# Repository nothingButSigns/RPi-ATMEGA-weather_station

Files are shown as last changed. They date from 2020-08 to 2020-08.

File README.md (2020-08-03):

# RPi-ATMEGA weather station
Project of weather station involving RPi, AVR microcontroller ATMEGA329P and radio transmission

The project concerns electronical and programming aspect of weather station.
The station itself is based on AVR microcontroller - ATMEGA 328p and set of sensors which allow to collect following data:
* temperature [°C]
* humidity [%RH]
* pressure [hPa]
* luminosity [lux]
* wind direction and wind speed [m/s]

The data is read every 1 h and sent via nRF24L01+PA radio tranceiver to Raspberry Pi 3B+ and saved in mysql database.

The repository contains eagle project of PCB board (THT) for the station and schematic. Libraries of parts which could not be found in EAGLE are included.

The project requires mySQL database to be installed on RPi.
MySQL database schema can be then imported with following terminal command:
```sh
$ mysql -u root -p [DB_NAME] < \path\user_name\Downloads\file.sql
```

C program (meteo_station.ino) was written in Arduino IDE 1.8.9.
Arduino bootloader was uploaded to ATMEGA 328P as instructed by [Nick Gammon](http://www.gammon.com.au/forum/?id=11637).
Following libraries are necessary:
* [Adafruit Sensor](https://github.com/adafruit/Adafruit_Sensor)
* [Wire](https://github.com/esp8266/Arduino/tree/master/libraries/Wire)
* [Adafruit BME280](https://github.com/adafruit/Adafruit_BME280_Library)
* [BH1750](https://github.com/claws/BH1750)
* [RF24](http://tmrh20.github.io/RF24)

C++ program written for RPi requires [RF24 library](https://github.com/nRF24/RF24) which contains essential dependencies (WiringPi & BCM2835) and [mySQL-cpp-connector] (https://dev.mysql.com/downloads/connector/cpp/)

The station is powered with 3.7 V NCR18650B connected to circuit via JACK socket. The battery is not included in schematic.

#BOM
| Q-ty | Part name | Value | Package | Description |
| --- | --- | ----- | --- | --- |
|1|ATMEGA328P|-|DIP|AVR Microcontroller|
|1|WIRELESS-NRF24L01-PA-EXT|-|-|2.4 GHz Wireless Module based on NRF24L01|
|1|BME280|-|-|Digital Humidity-Temperature-Pressure Sensor|
|1|BH1750|-|-|Digital Light Sensor|
|1|Lacrosse TX20|-|-|Wind speed and direction sensor|
|1|Quartz Crystal|8MHz|HC49/S|-|
|2|Electrolytic capacitor|0.1 uF|C2.5-3|-|
|1|Electrolytic capacitor|0.22 uF|C2.5-3|-|
|1|Electrolytic capacitor|4.7 uF|C2.5-3|-|
|2|Ceramic capacitor|22 pF|C2.5-3|-|
|3|Resistor|0 Ω |0204/5|-|
|1|Resistor|10 kΩ|0204/5|-|
|1|LFXXCVS|LF33CVS|TO220 S|Voltage regulator|
|1|JACK-PLUG|-|SPC4077|Plug to enable circuit powering with DC|
|1|4-pin terminal block|3.5 mm|-|Terminal block with round pad|

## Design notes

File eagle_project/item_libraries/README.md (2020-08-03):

Sources of used libraries:

https://www.diymodules.org/eagle
https://www.diymodules.org/eagle-show-library?id=1012211613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
https://github.com/shackspace/DARC/blob/master/doc/eagle/DARC/lf33.lbr

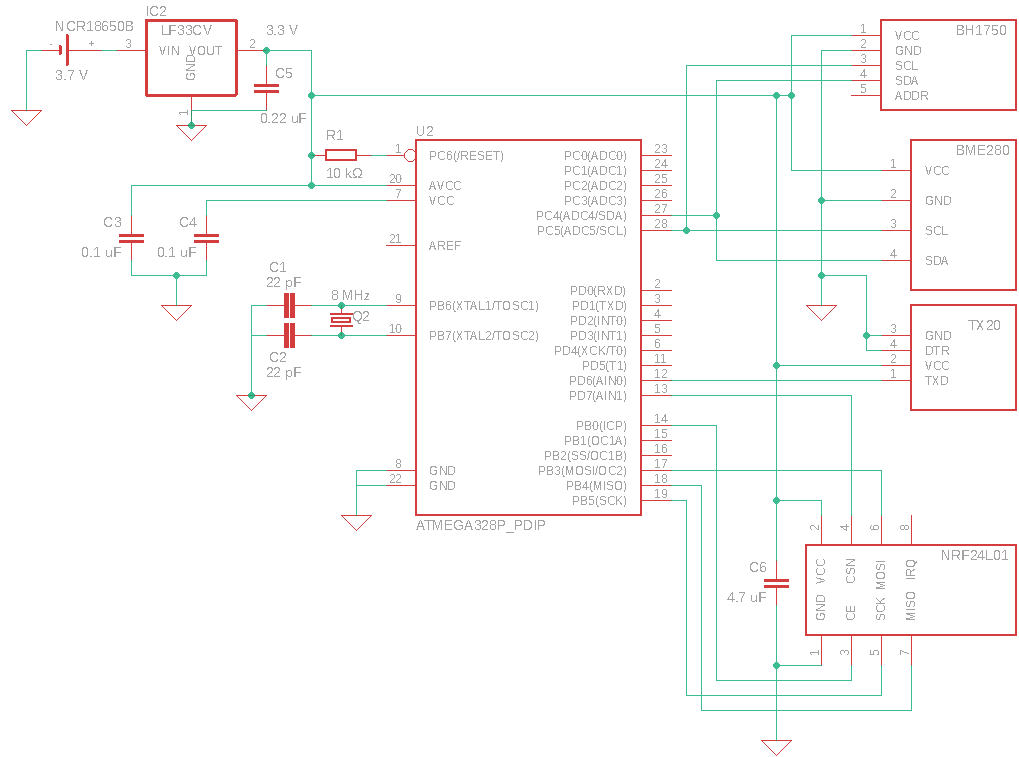
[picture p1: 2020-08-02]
eagle_project/schematic.png

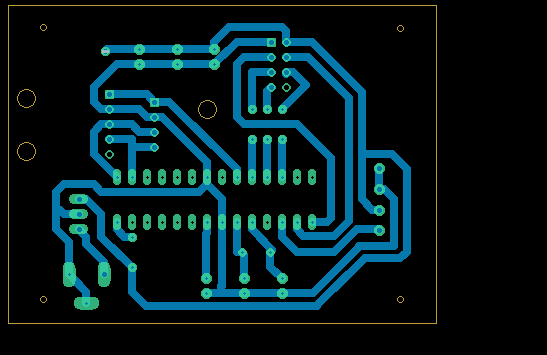
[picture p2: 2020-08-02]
eagle_project/board.png

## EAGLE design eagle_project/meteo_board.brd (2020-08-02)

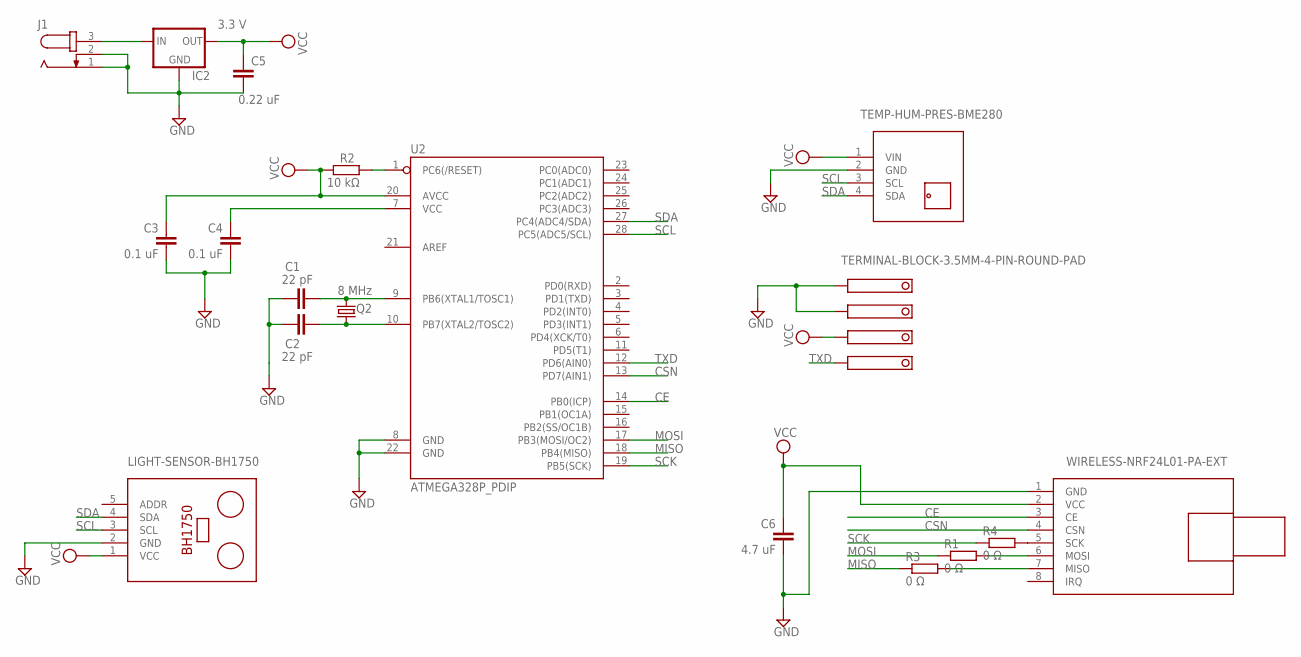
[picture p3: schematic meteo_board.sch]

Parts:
C1, C2: 22 pF; C2.5-3
C3, C4: 0.1 uF; C2.5-3
C5: 0.22 uF; C2.5-3
C6: 4.7 uF; C2.5-3
IC2: LFXXCVS; TO220S
J1: JACK-PLUG0; SPC4077
M1: WIRELESS-NRF24L01-PA-EXT
Q2: 8 MHz; HC49/S
R1, R3, R4: 0 Ω; 0204/5
R2: 10 kΩ; 0204/5
TX20: TERMINAL-BLOCK-3.5MM-4-PIN-ROUND-PAD; TERMINAL-BLOCK-4-PIN-3.5MM-ROUND-PAD
U2: ATMEGA328P_PDIP; DIL28-3
U$5: LIGHT-SENSOR-BH1750
U$6: TEMP-HUM-PRES-BME280

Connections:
CE: M1.3 (CE), U2.14 (PB0(ICP))
CSN: M1.4 (CSN), U2.13 (PD7(AIN1))
GND: C1.1, C2.1, C3.1, C4.1, C5.2, C6.1, IC2.2 (GND), J1.1, J1.2, M1.1 (GND), TX20.1, TX20.2, U2.8 (GND), U2.22 (GND), U$5.2 (GND), U$6.2 (GND)
MISO: R3.1, U2.18 (PB4(MISO))
MOSI: R1.1, U2.17 (PB3(MOSI/OC2))
unnamed: IC2.1 (IN), J1.3
unnamed: R2.2, U2.1 (PC6(/RESET))
unnamed: M1.5 (SCK), R4.2
unnamed: C1.2, Q2.2, U2.9 (PB6(XTAL1/TOSC1))
unnamed: C2.2, Q2.1, U2.10 (PB7(XTAL2/TOSC2))
unnamed: M1.6 (MOSI), R1.2
unnamed: M1.7 (MISO), R3.2
unnamed: C4.2, U2.7 (VCC)
SCK: R4.1, U2.19 (PB5(SCK))
SCL: U2.28 (PC5(ADC5/SCL)), U$5.3 (SCL), U$6.3 (SCL)
SDA: U2.27 (PC4(ADC4/SDA)), U$5.4 (SDA), U$6.4 (SDA)
TXD: TX20.4, U2.12 (PD6(AIN0))
VCC: C3.2, C5.1, C6.2, IC2.3 (OUT), M1.2 (VCC), R2.1, TX20.3, U2.20 (AVCC), U$5.1 (VCC), U$6.1 (VIN)

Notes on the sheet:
3.3 V

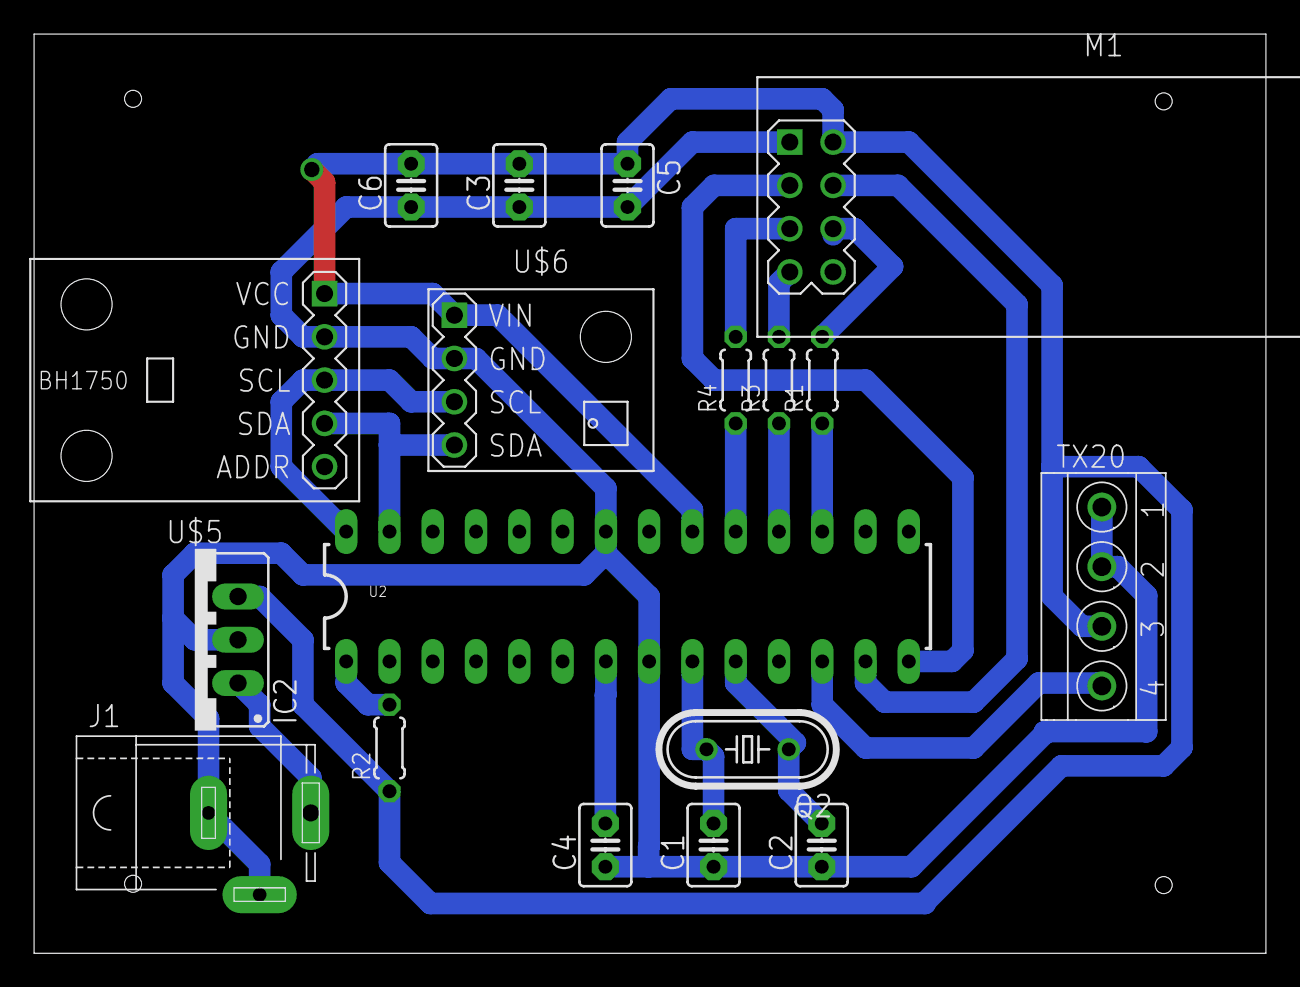
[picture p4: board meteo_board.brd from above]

Board: 2 copper layers, 72.3 x 54.0 mm, 18 parts (0 on the bottom side), 18 nets.

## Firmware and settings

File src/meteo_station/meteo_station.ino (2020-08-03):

#include <Wire.h>
#include <Adafruit_Sensor.h>
#include <Adafruit_BME280.h>
#include <BH1750.h>
#include <RF24.h>
#include <avr/sleep.h>
#include <avr/power.h>
#include <avr/wdt.h>

// define pin for Tx20
#define WINDpin 6
// define pins for nRF24L01+PA LNA
#define CE_PIN 8             
#define CSN_PIN 7
                 
const uint64_t transmit_pipe = 0xEEFDFDF0A2; // transmit pipe
RF24 radio(CE_PIN, CSN_PIN);

struct WeatherData {
    uint8_t lum;
    float temp;
    float hum;
    float press;
    float wind_speed;
    String wind_dir;
} weather;

Adafruit_BME280 bme;
BH1750 lightMeter;

unsigned long delayTime = 1000;
bool status;         // BME280 availability state ('true' if the sensor is available)
int bitlenght = -1;
bool data[41];
int watchdogIterations = 450;                  // number of WDT cycles to get ~1 h interval between data read
int currentIteration = watchdogIterations;     // enables data read right after powering on
byte adcsra = 0;


void delay2(unsigned long ms);
void getdata(void);
void interpretdata();

ISR(WDT_vect) {
   sleep_disable();               
   ADCSRA = adcsra;  // turn on ADC
}

void radiosetup()
{
  radio.powerUp();  
  radio.begin();
  radio.setCRCLength( RF24_CRC_16 ) ;
  radio.setDataRate( RF24_1MBPS );
  radio.setPayloadSize(32);
  radio.setChannel(0x4c);
  radio.setAutoAck( true ) ;
  radio.setPALevel( RF24_PA_HIGH ) ;
  radio.setRetries(5,15);
  radio.stopListening();
}

void setupSensors()
{
    radio.powerUp();
    void radiosetup();
    pinMode(WINDpin, INPUT);     
    Wire.begin();
    
    // set BH1750 sensor to read data once and go into sleep mode; set resolution to 4lx
    lightMeter.begin(BH1750::ONE_TIME_LOW_RES_MODE);
   
    status = bme.begin(0x76);
    if (!status) {
        while (1);
    }
}
  

void setup() { 
  // If reset occurs, check whether it was caused by WDT
  if(MCUSR & _BV(WDRF)) {
    MCUSR &= ~_BV(WDRF);              // reset reset-due-to-watchdog flag
    WDTCSR |= (_BV(WDCE) | _BV(WDE));  // enter watchdog configuration mode
    WDTCSR = 0x00;                     // disable WDT
  }  
  
  cli(); //disable interruptions
     
   WDTCSR |= (_BV(WDCE) | _BV(WDE));               // enter watchdog configuration mode
   WDTCSR =  _BV(WDIE) | _BV(WDP3) | _BV(WDP0);    // enable interrupts and set timer to ~8 sec
   wdt_reset();
  //re-enable interrupts    
  sei(); 
}

void loop() { 
  
  gotoSleep();
  
  if(++currentIteration >= watchdogIterations) {
    setupSensors();
    getdata();                                    
    interpretdata();                   
    weather.lum = lightMeter.readLightLevel(); 
    weather.temp = bme.readTemperature();        
    weather.press = bme.readPressure()/100.0;
    weather.hum = bme.readHumidity();

    radio.openWritingPipe(transmit_pipe);
    radio.write( &weather, sizeof(WeatherData)); 
    currentIteration = 1;
  }
   
}

// function to get datagram from Tx20
void getdata(){
  if (bitlenght <0){
     bitlenght = 1220; // duration of 1 bit [ms]
  }
 
   pinMode(WINDpin, OUTPUT);
   digitalWrite(WINDpin, HIGH);
   delay(100);
   
   digitalWrite(WINDpin, LOW );
   delay(500);
   
   pinMode(WINDpin, INPUT);
  
  
   while(digitalRead(WINDpin) == LOW){}  
   while(digitalRead(WINDpin) == HIGH){}
   while(digitalRead(WINDpin) == LOW){}

   for (int i=0 ; i<41 ; i++){  
     data[i] = (digitalRead(WINDpin) == LOW)? 0 : 1 ; 
     delay2(bitlenght);
 }

 interpretdata();
}

// function to retrieve wind speed and direction
void interpretdata(){
 
  // wind direction
  char DirBuffer = 0;
  for (int i =8 ; i> 4 ; i--){ 
    DirBuffer = DirBuffer << 1;
    DirBuffer |= (char)(data[i]^1);;
  }

   switch(DirBuffer) {
     case 0: weather.wind_dir="N"; break;
     case 1: weather.wind_dir="NNE"; break;;
     case 2: weather.wind_dir="NE"; break;
     case 3: weather.wind_dir="ENE"; break;
     case 4: weather.wind_dir="E"; break;
     case 5: weather.wind_dir="ESE"; break;
     case 6: weather.wind_dir="SE"; break;
     case 7: weather.wind_dir="SSE"; break;
     case 8: weather.wind_dir="S"; break;
     case 9: weather.wind_dir="SSW"; break;
     case 10: weather.wind_dir="SW"; break;
     case 11: weather.wind_dir="WSW"; break;
     case 12: weather.wind_dir="W"; break;
     case 13: weather.wind_dir="WNW"; break;
     case 14: weather.wind_dir="NW"; break;
     case 15: weather.wind_dir="NNW"; break;
   }

 
 int ws_buffer = 0;
 // wind speed data
 for (int i =9 ; i> 21 ; i++){
      ws_buffer |= (data[i]^1)<<(i-9);     
 }

 ws_buffer &=~(1<<11|1<<10|1<<9); 
 weather.wind_speed = ws_buffer * 0.1;  
}

void gotoSleep(void)
{
   adcsra = ADCSRA;                       // save ADC state
   ADCSRA = 0;                            // turn off ADC 
   set_sleep_mode(SLEEP_MODE_PWR_DOWN);   // use power down sleep mode
   sleep_enable();                        // enable sleep mode
   sleep_cpu();                   
}

void delay2(unsigned long ms){
  unsigned long start = micros();
  while (micros() - start <= ms);
}

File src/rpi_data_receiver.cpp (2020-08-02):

#include <mysql_connection.h>
#include <cppconn/driver.h>
#include <cppconn/statement.h>
#include <cppconn/exception.h>
#include <cppconn/prepared_statement.h>
#include <inttypes.h>

#include <RF24.h>
#include <wiringPi.h>

/* Create instance of class RF24 to receive radio data.
 * 	Connection of nRF24L01 transceiver module to RPi:
 *  CE -> RPI_V2_GPIO_P1_22
 *	CSN -> RPI_V2_GPIO_P1_24
 *	SPI speed [MHZ] -> BCM2835_SPI_SPEED_8MHZ
 */

RF24 radio(RPI_V2_GPIO_P1_22, RPI_V2_GPIO_P1_24, BCM2835_SPI_SPEED_8MHZ);
/* Writing/receiving pipes created according to nRF24L01 specification:
 * pipes[0] -> writing pipe
 * pipes[1] -> reading pipe; it's address is the same as address
 * of writing pipe in weather station
 */
const uint64_t pipes[2] = { 0xeefdfdf0ec, 0xa2ll};

/* Data to connect to mySQL database in order to save received data.
 * MYSQL_USER and MYSQL_PASSWD defines should be replaced with
 * Your own user data
 */
#define HOST "localhost"
#define MYSQL_USER "randomuser"
#define MYSQL_PASSWD "password"
#define MYSQL_DATABASE "sensor_data"

struct __attribute__((__packed__)) WeatherData {
	uint8_t lum;
    float temp;
    float hum;
    float press;
    float w_speed;
    const char* w_dir;
} weather;

void setup_radio()
{
  radio.begin();
  /* data below can be adjusted to acquire efficient
   * transmission in case-specific conditions
   * such as distance between weather station and receiver
   * or presence of any physical obstacles (e.g. walls)
   */
  radio.setPayloadSize(32);
  radio.setRetries(5,15);
  radio.setAutoAck(true);
  radio.setPALevel(RF24_PA_HIGH);
  radio.setChannel(0x4c);
  radio.setDataRate(RF24_1MBPS);
  radio.setCRCLength(RF24_CRC_16);
  delay(100);

      radio.openWritingPipe(pipes[0]);
      radio.openReadingPipe(1,pipes[1]);
}


void saveData(WeatherData *weather)
{
    sql::Driver * driver;
    sql::Connection *conn;
    sql::Statement *stat;
    sql::PreparedStatement *prep_stat;


    driver = get_driver_instance();
    conn = driver->connect(HOST, MYSQL_USER, MYSQL_PASSWD);
    stat = conn->createStatement();
    stat->execute("USE sensor_data");


            prep_stat = conn->prepareStatement("INSERT INTO weather_data(Date, Time, Temperature, Humidity, Pressure, Luminosity, Wind_dir, Wind_speed) VALUES(NOW(), NOW(),?, ?, ?, ?, ?, ?)");
            prep_stat->setDouble(1,(*weather).temp);
            prep_stat->setDouble(2,(*weather).hum);
            prep_stat->setDouble(3,(*weather).press);
            prep_stat->setInt(4,(*weather).lum);
            prep_stat->setString(5,(*weather).w_dir);
            prep_stat->setDouble(6,(*weather).w_speed);


            prep_stat->execute();

    delete prep_stat;
    delete stat;
    delete conn;
    delete driver;

}


void waitForData()
{
    uint8_t pipeNum;
    setup_radio();
    radio.startListening();

 while(1) {

    if ( radio.available(&pipeNum) ) {

      while (radio.available())
      {
        if (pipeNum) {
			radio.read(&weather, sizeof(WeatherData) );
			saveData(&weather);
        }
      }
    }
    }
}


int main()
{

	waitForData();


	return 0;
}

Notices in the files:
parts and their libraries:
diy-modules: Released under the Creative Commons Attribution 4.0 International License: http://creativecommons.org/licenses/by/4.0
